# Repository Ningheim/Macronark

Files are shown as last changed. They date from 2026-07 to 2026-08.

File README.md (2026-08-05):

# Macronark, a HXH inspired macropad
A macropad inspired by Shalnark's ability in a popular manga called Hunter X Hunter by Yoshihiro Togashi

The "Macronark" is a 12 key macropad with RGB backlit keys. It uses QMK firmware and is upgradable with a 6-pin JST port on the back of the PCB.

## Features:
- Full PLA Shalnark inspired case
- 12 blank DSA keys
- 12 SK6812 MINI-E LEDs for backlighting

## CAD Model:
Everything is fitted together with 6 M3 bolts and heatset inserts. The PCB sits in flush with the case but there is 1 M3 screw hole if you'd like to secure it to your own case.

It's in 2 parts, 1 part for the body and another for the cover.
EmptyCase
Made in Onshape
At a later time a seperate PCB will be used to fill the top portion of the case. More RGB LEDs will be used to light up the eye cutouts and a OLED screen will go inside the mouth just as the series depicts it.

## PCB:
The PCB was made in KiCAD, The silkscreen was imported from a Figma image.

#### Schematic
Schematic

#### PCB
PCB
3DPCB

# Finished Product
Once you've printed everything and inserted/soldered all of the components, the result should look like this! (With keycaps of your choice of course 😅)
Product

## Firmware Overview:
This hackpad uses [QMK](https://qmk.fm/) firmware.
- To turn on/off the RGB backlighting, press and hold the top-left key and the bottom-right key together
- All keys act as macros to be assigned to whatever you'd like.

## BOM:
Here's everything you need to make this hackpad
```
-1x Seeed XIAO RP2040
-12x through-hole 1N4148 Diodes
-12x Cherry MX Switches
-12x white blank DSA keycaps
-12x SK6812 MINI-E LEDs
-6x M3x16mm screws
-6x M3x5mx4mm heatset inserts
-1x Case, All 3D Printed
```

Note: Fixed source file issue about the 3mf files. Changed it to steps and stls

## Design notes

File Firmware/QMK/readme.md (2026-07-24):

# blackvoice

blackvoice

*A short description of the keyboard/project*

* Keyboard Maintainer: [Freedom-Mawuli Nyadroh](https://github.com/RocketMakr)
* Hardware Supported: *The PCBs, controllers supported*
* Hardware Availability: *Links to where you can find this hardware*

Make example for this keyboard (after setting up your build environment):

    make blackvoice:default

Flashing example for this keyboard:

    make blackvoice:default:flash

See the [build environment setup](https://docs.qmk.fm/#/getting_started_build_tools) and the [make instructions](https://docs.qmk.fm/#/getting_started_make_guide) for more information. Brand new to QMK? Start with our [Complete Newbs Guide](https://docs.qmk.fm/#/newbs).

## Bootloader

Enter the bootloader in 3 ways:

* **Bootmagic reset**: Hold down the key at (0,0) in the matrix (usually the top left key or Escape) and plug in the keyboard
* **Physical reset button**: Briefly press the button on the back of the PCB - some may have pads you must short instead
* **Keycode in layout**: Press the key mapped to `QK_BOOT` if it is available

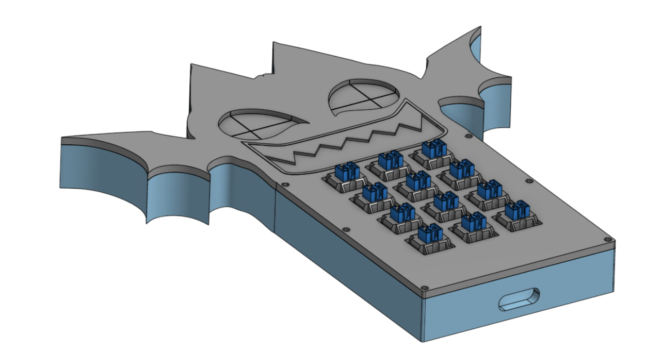
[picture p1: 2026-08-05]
assets/Product.png

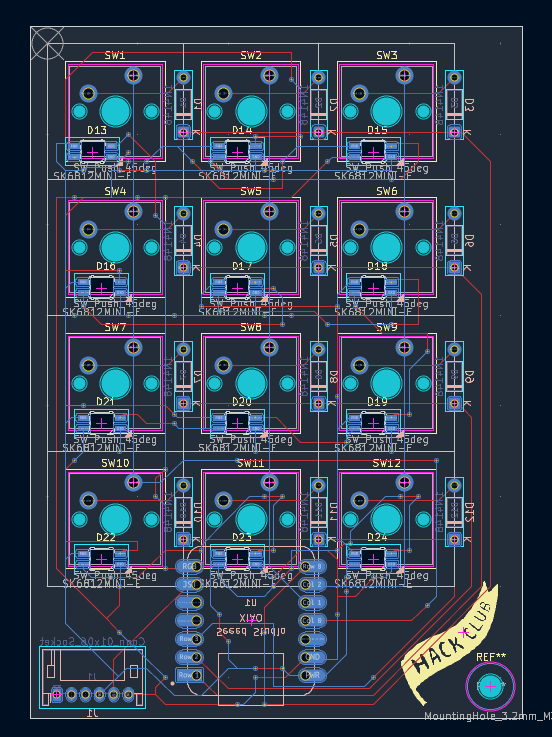
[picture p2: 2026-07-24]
assets/PCB.png

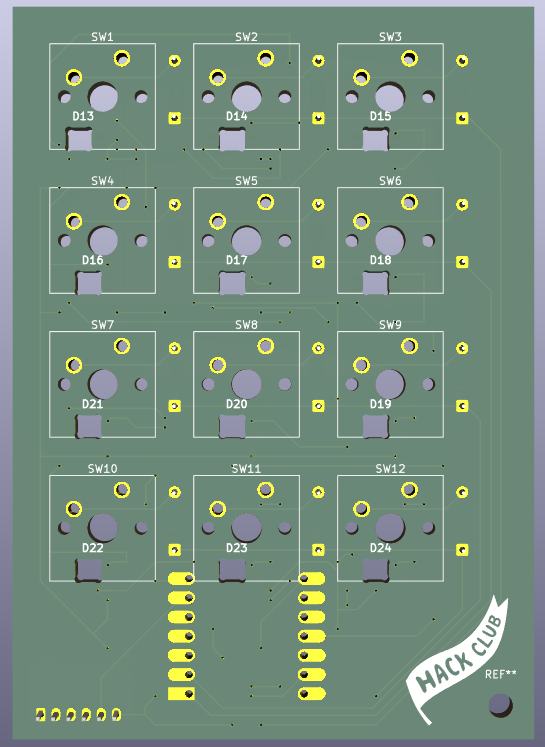
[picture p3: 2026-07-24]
assets/3DPCB.png

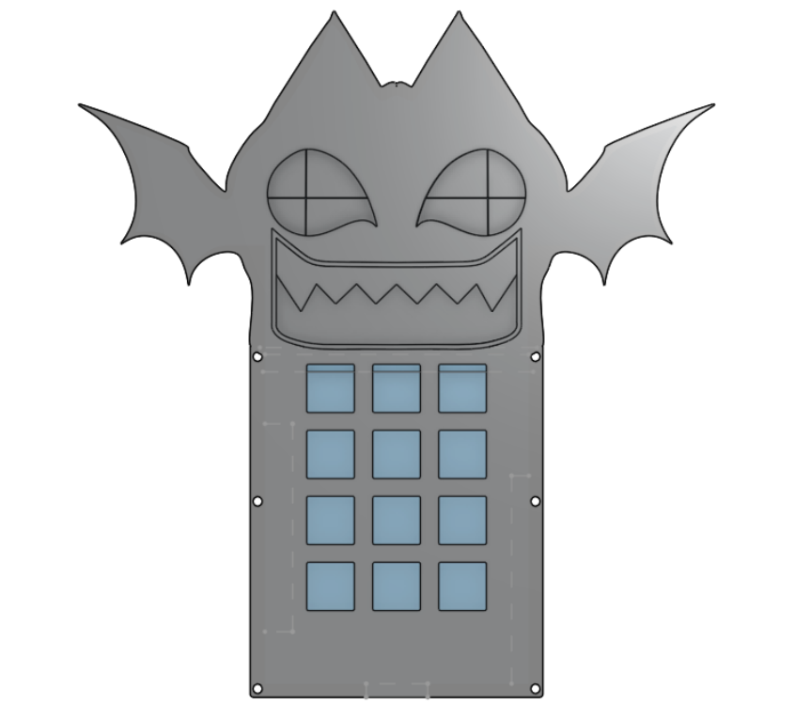
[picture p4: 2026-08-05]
assets/CAD.png

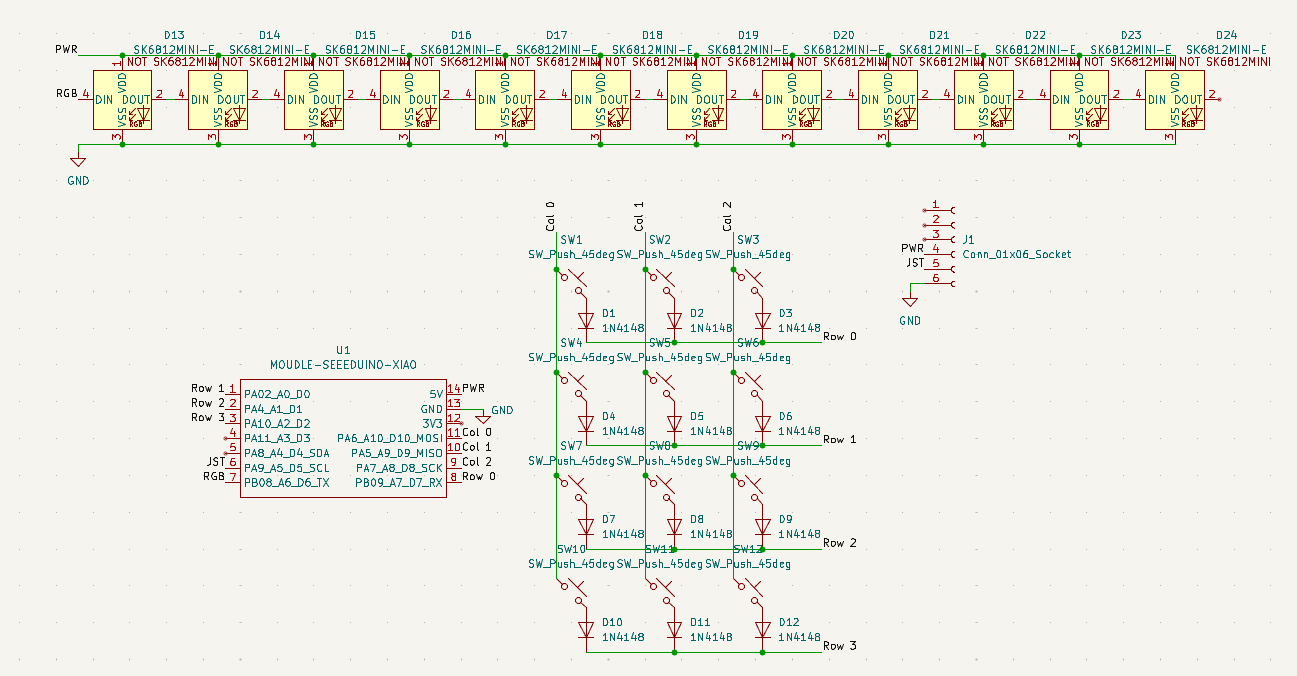
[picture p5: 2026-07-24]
assets/SCH.png

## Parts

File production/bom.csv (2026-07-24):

Designator | Footprint | Quantity | Value | LCSC Part #
 | 462f2333-586c-4cc8-b04d-9995b911b9d8 | 1
D1, D10, D11, D12, D2, D3, D4, D5, D6, D7, D8, D9 | D_DO-35_SOD27_P7.62mm_Horizontal | 12 | 1N4148
D13, D14, D15, D16, D17, D18, D19, D20, D21, D22, D23, D24 | SK6812MINI-E_fixed | 12 | SK6812MINI-E
J1 | JST_PH_S6B-PH-K_1x06_P2.00mm_Horizontal | 1 | Conn_01x06_Socket
SW1, SW10, SW11, SW12, SW2, SW3, SW4, SW5, SW6, SW7, SW8, SW9 | SW_Cherry_MX_1.00u_PCB | 12 | SW_Push_45deg
U1 | XIAO-Generic-Hybrid-14P-2.54-21X17.8MM | 1 | MOUDLE-SEEEDUINO-XIAO

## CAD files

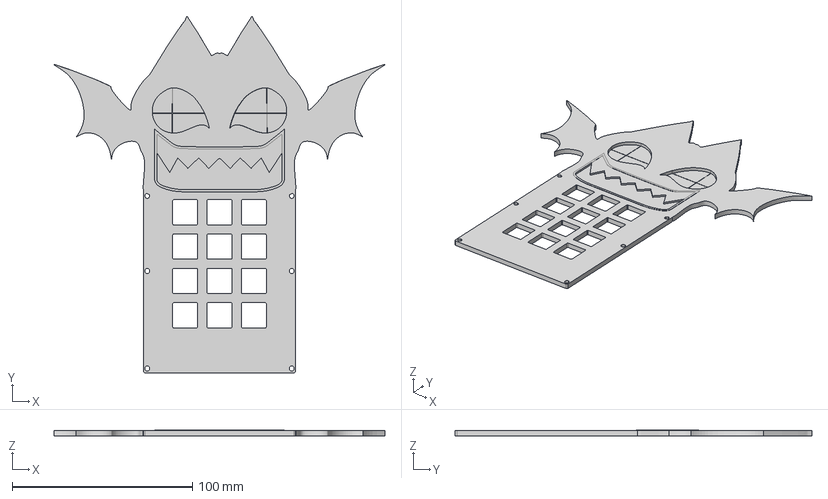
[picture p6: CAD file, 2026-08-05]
CAD/MainCase - Part 2.step
183.7 x 197.9 x 3.30 mm

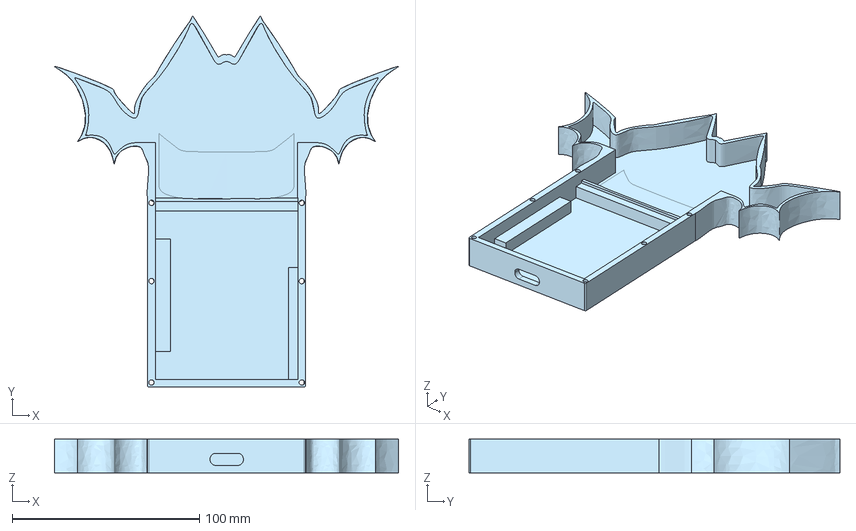
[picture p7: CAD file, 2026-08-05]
CAD/MainCase - Part 1.step
183.7 x 197.9 x 18.0 mm

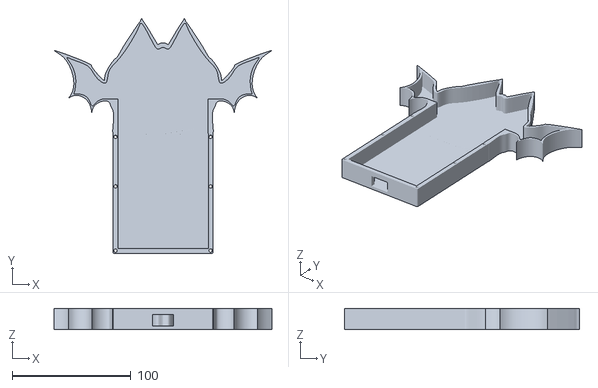
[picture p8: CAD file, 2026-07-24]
production/CaseCover.stl
183.7 x 197.9 x 18.0

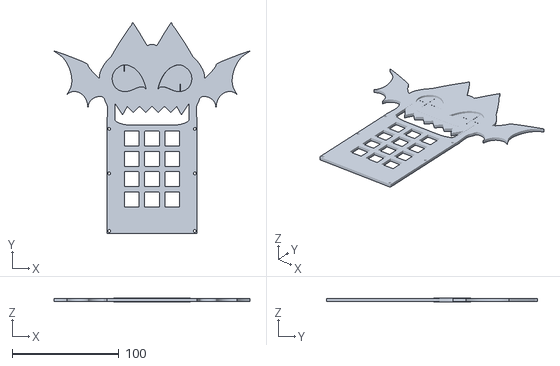
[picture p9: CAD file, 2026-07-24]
production/CaseBody.stl
183.7 x 197.9 x 3.30

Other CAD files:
CAD/MainCase - Part 1.stl
CAD/MainCase - Part 2.stl

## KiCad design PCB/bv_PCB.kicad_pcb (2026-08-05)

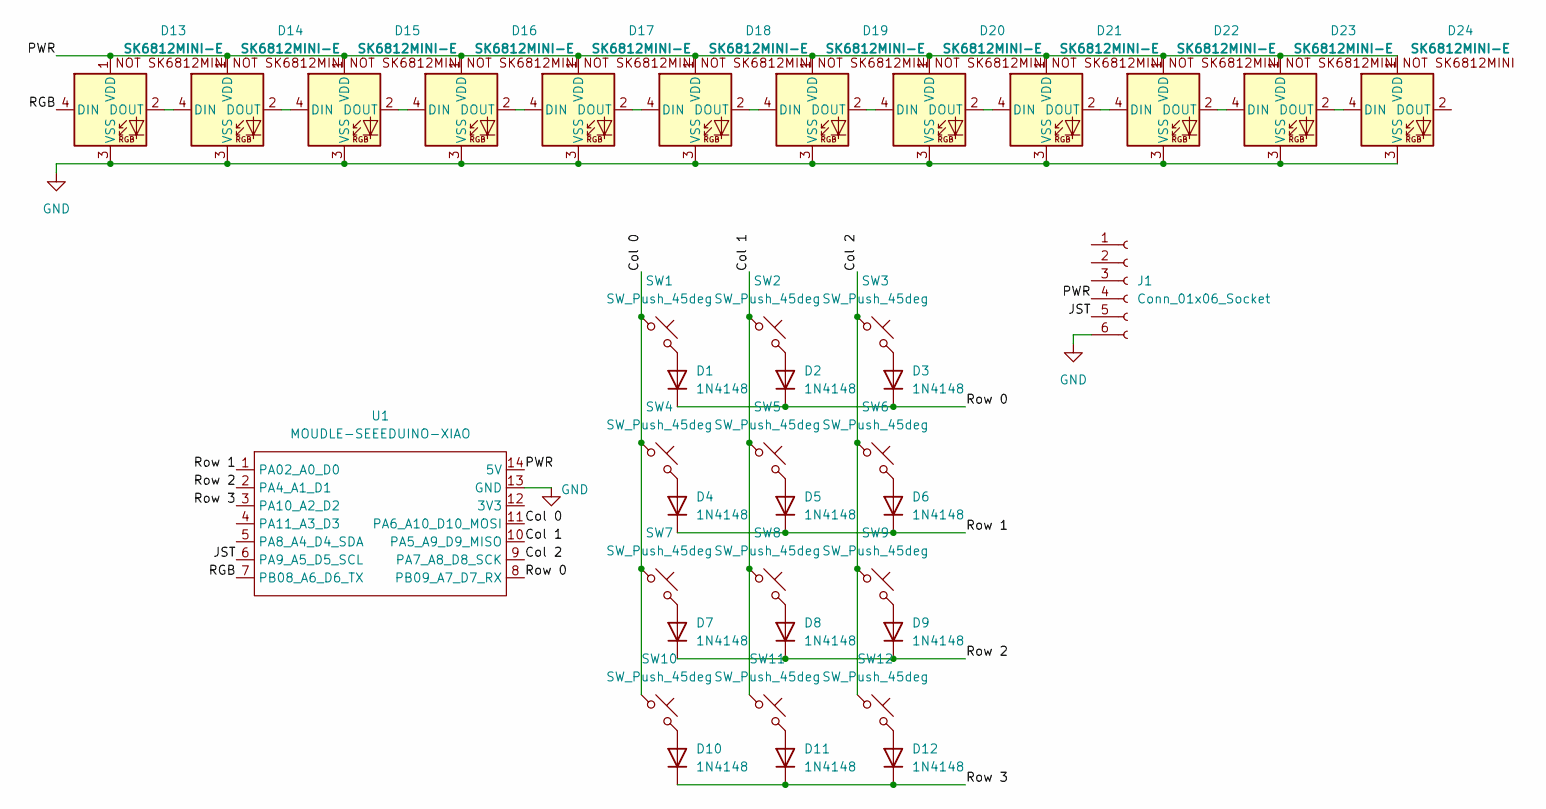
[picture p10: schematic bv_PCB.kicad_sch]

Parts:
D1, D2, D3, D4, D5, D6, D7, D8, D9, D10, D11, D12: 1N4148; D_DO-35_SOD27_P7.62mm_Horizontal
D13, D14, D15, D16, D17, D18, D19, D20, D21, D22, D23, D24: SK6812MINI-E; SK6812MINI-E_fixed
J1: Conn_01x06_Socket; JST_PH_S6B-PH-K_1x06_P2.00mm_Horizontal
SW1, SW2, SW3, SW4, SW5, SW6, SW7, SW8, SW9, SW10, SW11, SW12: SW_Push_45deg; SW_Cherry_MX_1.00u_PCB
U1: MOUDLE-SEEEDUINO-XIAO; XIAO-Generic-Hybrid-14P-2.54-21X17.8MM

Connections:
/Col 0: SW1.1, SW4.1, SW7.1, SW10.1, U1.11 (PA6_A10_D10_MOSI)
/Col 1: SW2.1, SW5.1, SW8.1, SW11.1, U1.10 (PA5_A9_D9_MISO)
/Col 2: SW3.1, SW6.1, SW9.1, SW12.1, U1.9 (PA7_A8_D8_SCK)
/JST: J1.5, U1.6 (PA9_A5_D5_SCL)
/PWR: D13.1 (VDD), D14.1 (VDD), D15.1 (VDD), D16.1 (VDD), D17.1 (VDD), D18.1 (VDD), D19.1 (VDD), D20.1 (VDD), D21.1 (VDD), D22.1 (VDD), D23.1 (VDD), D24.1 (VDD), J1.4, U1.14 (5V)
/RGB: D13.4 (DIN), U1.7 (PB08_A6_D6_TX)
/Row 0: D1.1 (K), D2.1 (K), D3.1 (K), U1.8 (PB09_A7_D7_RX)
/Row 1: D4.1 (K), D5.1 (K), D6.1 (K), U1.1 (PA02_A0_D0)
/Row 2: D7.1 (K), D8.1 (K), D9.1 (K), U1.2 (PA4_A1_D1)
/Row 3: D10.1 (K), D11.1 (K), D12.1 (K), U1.3 (PA10_A2_D2)
GND: D13.3 (VSS), D14.3 (VSS), D15.3 (VSS), D16.3 (VSS), D17.3 (VSS), D18.3 (VSS), D19.3 (VSS), D20.3 (VSS), D21.3 (VSS), D22.3 (VSS), D23.3 (VSS), D24.3 (VSS), J1.6, U1.13 (GND)
unnamed: D1.2 (A), SW1.2
unnamed: D2.2 (A), SW2.2
unnamed: D3.2 (A), SW3.2
unnamed: D4.2 (A), SW4.2
unnamed: D5.2 (A), SW5.2
unnamed: D6.2 (A), SW6.2
unnamed: D7.2 (A), SW7.2
unnamed: D8.2 (A), SW8.2
unnamed: D9.2 (A), SW9.2
unnamed: D10.2 (A), SW10.2
unnamed: D11.2 (A), SW11.2
unnamed: D12.2 (A), SW12.2
unnamed: D13.2 (DOUT), D14.4 (DIN)
unnamed: D14.2 (DOUT), D15.4 (DIN)
unnamed: D15.2 (DOUT), D16.4 (DIN)
unnamed: D16.2 (DOUT), D17.4 (DIN)
unnamed: D17.2 (DOUT), D18.4 (DIN)
unnamed: D18.2 (DOUT), D19.4 (DIN)
unnamed: D19.2 (DOUT), D20.4 (DIN)
unnamed: D20.2 (DOUT), D21.4 (DIN)
unnamed: D21.2 (DOUT), D22.4 (DIN)
unnamed: D22.2 (DOUT), D23.4 (DIN)
unnamed: D23.2 (DOUT), D24.4 (DIN)

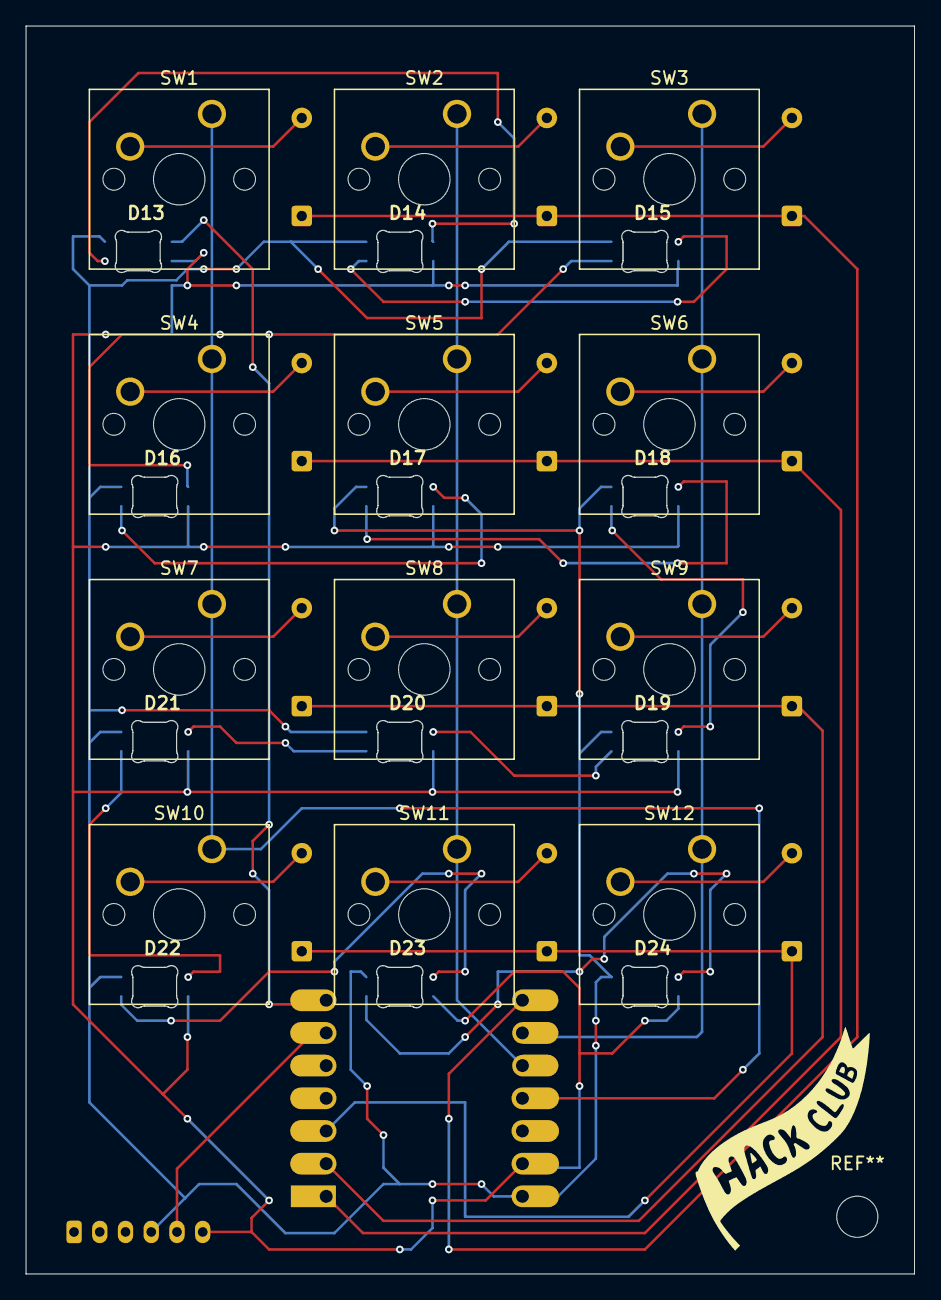
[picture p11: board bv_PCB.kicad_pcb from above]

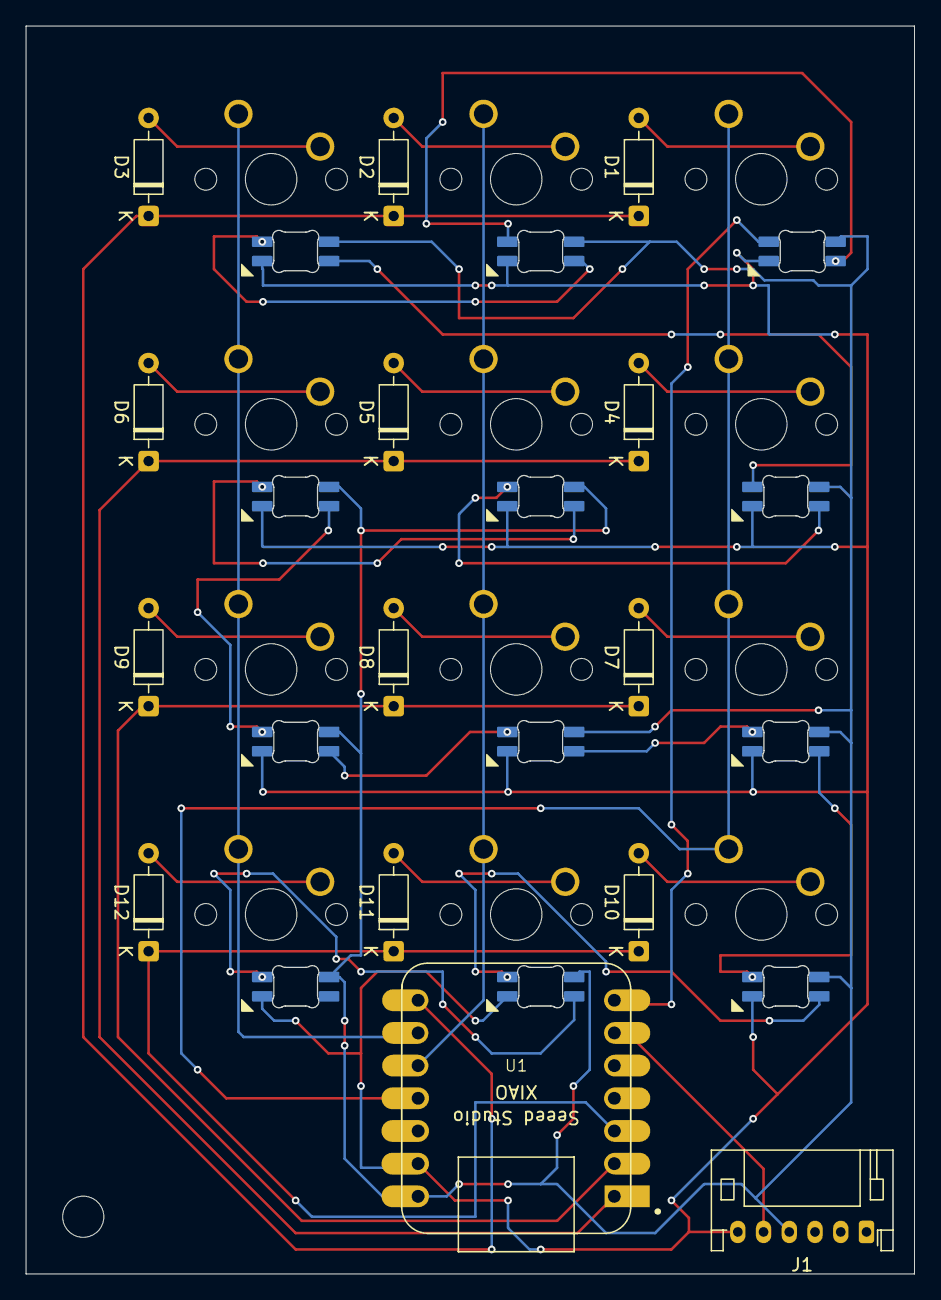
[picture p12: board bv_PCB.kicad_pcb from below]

Board: 2 copper layers, 69.1 x 97.0 mm, 38 parts (14 on the bottom side), 34 nets.

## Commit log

2026-07-24 Nearly Done with KiCAD
    [bv_PCB.kicad_pcb, bv_PCB.kicad_sch]
2026-07-24 Refining Repository
    [BVCase.3mf, CaseBody.stl, CaseCover.stl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]
2026-07-24 Finished Everything
    [bv_PCB.kicad_pcb]
2026-08-05 CAD fix
    [BVCase.3mf, MainCase - Part 1.step, MainCase - Part 1.stl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]
